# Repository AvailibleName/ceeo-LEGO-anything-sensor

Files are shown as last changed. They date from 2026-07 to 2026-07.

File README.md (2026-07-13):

## Bill of Materials (BOM)

To build the hardware for this device, you will need the following components:

- **Breadboard:** [Amazon Link](https://a.co/d/08REgV1U)
- **Microcontroller (Seeed XIAO nRF52840):** [Amazon Link](https://a.co/d/0hvDNsSc)
- **Battery:** [Amazon Link](https://a.co/d/0hvjeEuI)
- **RGB Button:** [Amazon Link](https://a.co/d/0b4CaRvc)
- **NFC Reader (MFRC522/WS1850S):** [Amazon Link](https://a.co/d/06IRiosf)
- **Misc:** Jumper wires, NFC cards/tags, and the actual sensors you wish to connect (e.g., VEML6040 Color Sensor, I2C OLED).

---

## Getting Started

### 1. Clone this Repository
First, download the repository so you have access to both the Arduino firmware and the Python library:
```bash
git clone https://github.com/AvailibleName/ceeo-LEGO-anything-sensor
cd ceeo-LEGO-anything-sensor
```
*(The Arduino code is located right in the root of this folder, and the custom Python library is in the `python_lib/` directory).*

---

## Wiring Guide

> [!IMPORTANT]
> You need to remove the housing from the NFC reader.

### Power
- **XIAO `3V3`** $\rightarrow$ Route power *directly* to the NFC Sensor VCC and RGB Button power (L1), since they are inside the housing and do not connect to the exposed breadboard. Also route `3V3` to the Breadboard VCC hookup for hot-swappable sensors.
- **XIAO `GND`** $\rightarrow$ Route ground *directly* to the NFC Sensor GND and RGB Button. Also route `GND` to the Breadboard GND hookup.

### RGB Button UI
- **XIAO `D0`** $\rightarrow$ Button contact/switch (Middle pin labeled **NO** on the switch)
- **XIAO `D1`** $\rightarrow$ Blue LED (Pin **L2** on the switch)
- **XIAO `D2`** $\rightarrow$ 100 $\Omega$ resistor $\rightarrow$ Green LED (Pin **L4** on the switch)
- **XIAO `D3`** $\rightarrow$ 100 $\Omega$ resistor $\rightarrow$ Red LED (Pin **L3** on the switch)
- **XIAO `3V3`** $\rightarrow$ Power (Pin **L1** on the switch)

### I2C Bus (Sensors & NFC)
- **XIAO `D4` (SDA)** $\rightarrow$ Route *separately* directly to the NFC Reader SDA, and also to the Breadboard SDA hookup.
- **XIAO `D5` (SCL)** $\rightarrow$ Route *separately* directly to the NFC Reader SCL, and also to the Breadboard SCL hookup.
*(Note: The custom sensors will be hot-swapped and their wiring will be connected to the hookups for I2C routed to the breadboard).*

---

## Build Instructions

1. **3D Printing the Housing** (files in `CAD/` folder): 
   - Print the main body housing **button-side-down** using **organic supports** set to **everywhere**.
   - The top plate should not need supports.
2. **Wiring**: Wire all components according to the guide above.
3. **Flashing Firmware**: 
   - **Flash the Arduino firmware onto the XIAO *before* assembling the housing.** Once assembled, the tiny reset (RST) button on the XIAO used for entering Bootloader mode will not be accessible!
4. **Assembly**: 
   - Trim the tabs at the base of the Grove connector on the NFC reader.
   - Bend the Grove port upwards so that it does not stick out too far to put the top plate on.
   - Route the cables going up to the breadboard *before* sliding the breadboard into the bottom housing (it won't be accessible after).
   - Slide all components into the bottom housing.
   - Superglue the top plate to the opening.
   - Superglue two LEGO 6x2 plates to the top, and two more LEGO 6x2 plates to the bottom.

---

## Firmware Setup

1. **Install Arduino IDE**: Download and install the [Arduino IDE](https://www.arduino.cc/en/software).
2. **Add Board Manager URL**: Open Arduino IDE. Go to `File > Preferences` and add `https://adafruit.github.io/arduino-board-index/package_adafruit_index.json` to the "Additional Boards Manager URLs" field.
3. **Install Board Support**: Go to `Tools > Board > Boards Manager...`, search for `Adafruit nRF52`, and install the **Adafruit nRF52 by Adafruit** package.
4. **Select Board**: Go to `Tools > Board > Adafruit nRF52 Boards` and select **Seeed XIAO nRF52840**.
5. **Install Libraries**: Go to `Tools > Manage Libraries...` and ensure you have any required libraries installed (e.g., `Adafruit TinyUSB Library` should be installed by the board package, but verify if needed).
6. **Flash the Code**: Open the `LegoSmartSensor.ino` file (located in the folder you just cloned) in the Arduino IDE, select the correct COM port under `Tools > Port`, and click the **Upload** arrow to flash the firmware to the XIAO. 

> [!TIP]
> If you ever need to flash new firmware after the device is assembled, hold the RGB button down for **10 seconds** while the device is on. The light will turn solid blue, and the device will reboot into DFU Bootloader mode, allowing you to upload code over USB.

---

## Software Setup (Python)

To communicate with the hardware, we use a fork of the `legoeducation` Python library that has been extended to support our custom sensors. For documentation on the original base library, refer to the [LEGOEducation GitHub](https://github.com/LEGO/LEGOEducation/blob/main/README.md).

### 1. Set up a Virtual Environment
We recommend creating a Python virtual environment inside the cloned folder to house the custom library:

```bash
# Create the virtual environment (use --system-site-packages if you have Bleak installed globally)
python3 -m venv --system-site-packages venv

# Activate it
source venv/bin/activate
```

### 2. Install the Custom Library
The custom library is located in the `python_lib/legoeducation` folder of this repository. You can copy it directly into your virtual environment:

```bash
cp -r python_lib/legoeducation venv/lib/python3.14/site-packages/
```
*(Make sure to adjust `python3.14` to match your actual Python version!)*

### 3. Running the Example
Once activated, run the provided boilerplate connection script to test your connection:
```bash
python3 examples/example.py
```

---

## Custom Sensor Documentation

By extending the `legoeducation` library in this repo, we can support totally custom hardware modules. 
### Color Sensor (VEML6040)
- **Product ID**: `61` (Emulates the official LEGO SPIKE Color Sensor)
- **Features**: This firmware module reads data from a VEML6040 I2C sensor and packages it to behave *identically* to an official LEGO Color Sensor.
- **Usage**: Since it acts identically to the official hardware, you can just use the standard legoeducation `ColorSensor` class. Please refer directly to the [original LEGOEducation library documentation](https://github.com/LEGO/LEGOEducation/blob/main/README.md) for full instructions on how to use it!

### OLED Display (`OledSensor`)
- **Product ID**: `530`
- **Notification ID**: `20`
- **Features**: 2-way data flow over BLE. The XIAO routes raw payload bytes directly into the C++ `handleDataReceived()` function.
- **Python Methods Available**:
  - `oled.print_text("Hello World")`: Prints standard ASCII text to the screen.
  - `oled.write_array(data)`: Renders raw 2D pixel arrays.
  - `oled._send_commands(bytes([0x06]))`: Clears the display.
  - `oled._send_commands(bytes([0x05, col, page]))`: Sets cursor position.
  - `oled._send_commands(bytes([0x03]))`: Starts hardware scroll.
  - `oled._send_commands(bytes([0x04]))`: Stops hardware scroll.

---

## Adding Your Own Custom Sensors (AI Generator)

Because adding a completely custom sensor requires both writing a C++ driver for the microcontroller AND modifying the Python `legoeducation` library on your PC to parse the data, we have included an AI Prompt generator to do the heavy lifting for you!

You can find the AI prompt template in the `AI_SENSOR_PROMPT.md` file in the root of this repository. 

To use it:
1. Open `AI_SENSOR_PROMPT.md`.
2. Choose **Option 1** if you are using an agentic AI that can read your local files (like Cursor, Claude Code, or Antigravity), or **Option 2** if you are pasting into a web chatbot (like ChatGPT or Claude Web).
3. Fill in the bracketed placeholders (`[LIKE THIS]`) with the specific I2C address and details of the hardware module you want to add.
4. The AI will instantly generate the `MySensor.cpp` and `MySensor.h` files for your Arduino firmware, AND provide the exact Python snippets you need to paste into `python_lib/legoeducation/rpc_message.py` and `device.py` to seamlessly parse the new data!

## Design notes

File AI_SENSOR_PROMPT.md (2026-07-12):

# AI Prompt Generator: LEGO Smart Sensor Driver

This document contains two AI prompts depending on what kind of AI you are using.

**Before you copy either prompt, make sure to replace the bracketed placeholders `[LIKE THIS]` with your specific sensor details!**

---

## Option 1: For Agentic AI (Antigravity, Claude Code, Cursor)
Use this prompt if the AI **has access to your local filesystem** and can read your code directly.

**[COPY BELOW THIS LINE]**

I am building a custom C++ firmware for a Seeed XIAO nRF52840 that emulates a LEGO Education sensor brick (like a Color Sensor, Matrix Display, or Distance Sensor) over BLE. 

The repository is located here: **[INSERT REPOSITORY FILEPATH HERE, e.g., /home/user/LegoSmartSensor]**

Please explore the repository and read all the `.cpp`, `.h`, and `.ino` files (especially `sensor_base.h`, `ble_emulator.cpp`, and the Python code in `python_lib/legoeducation`) to fully understand how the architecture handles device auto-detection, BLE notification packing, and 2-way data routing.

I need you to write a custom sensor driver for this hardware:
- **My Sensor/Addon Name:** [INSERT YOUR SENSOR NAME/MODEL HERE, e.g., TCS34725 I2C Color Sensor]
- **My Sensor's I2C Address:** [INSERT I2C ADDRESS, e.g., 0x29]
- **The specific data I want to extract/send:** [INSERT WHAT DATA YOU WANT, e.g., "I want to extract raw RGB values and convert them to HSV."]

Please implement the C++ `.cpp` and `.h` files inheriting from `LegoSensor`, and the Python payload/device classes for the `legoeducation` library.

**CRITICAL RULES & COMMON ISSUES TO AVOID:**
1. **No I2C Timeouts:** The Adafruit nRF52 Arduino Core's `TwoWire` class does **NOT** support `Wire.setWireTimeout()`. Do not attempt to use it or the code will fail to compile.
2. **No Serial Blocking:** This device often runs on battery power disconnected from USB. Never use `while(!Serial)` or any blocking serial wait loops, as this will completely freeze the device when unplugged. Always use safe wrappers like `if (Serial) { Serial.print(...); }`.
3. **Graceful Disconnects:** Ensure your `isConnected()` function correctly catches if the device is suddenly unplugged from the I2C bus, and ensure the main `buildNotification()` loop does not hang indefinitely waiting for bytes from an unresponsive I2C sensor.
4. **Integration:** Tell me exactly what lines to add to `SensorManager::detectSensors()` and where to inject the Python code.

---

## Option 2: For Chatbots (ChatGPT, Claude Web, Gemini)
Use this prompt if the AI **does not have access to your filesystem** and needs the architecture explained to it.

**[COPY BELOW THIS LINE]**

I am building a custom C++ firmware for a Seeed XIAO nRF52840 that emulates a LEGO Education sensor brick (like a Color Sensor, Matrix Display, or Distance Sensor) over BLE. 

I need you to write a custom sensor driver class that I can drop into my firmware.

### 1. The Target Hardware
- **My Microcontroller:** Seeed XIAO nRF52840 (Arduino Core)
- **My Sensor/Addon Name:** [INSERT YOUR SENSOR NAME/MODEL HERE, e.g., TCS34725 I2C Color Sensor]
- **My Sensor's I2C Address:** [INSERT I2C ADDRESS, e.g., 0x29]
- **The specific data I want to extract/send:** [INSERT WHAT DATA YOU WANT, e.g., "I want to extract raw RGB values and convert them to HSV."]

### 2. The Firmware Architecture
The firmware is already written and has an automatic hardware-detection system. It works like this:
1. `SensorManager` continuously polls the I2C bus. If it detects a device at a specific I2C address, it swaps a global pointer to use that specific sensor's driver class.
2. The `BleEmulator` automatically calls `buildNotification()` on the active sensor 10 times a second.
3. The `BleEmulator` automatically wraps the output of `buildNotification()` into the standard LEGO `DEVICE_NOTIFICATION` (MsgID 60) envelope, so the sensor driver ONLY needs to provide the sensor-specific inner payload bytes.

### 3. The Required Interface
You must create a `.h` and `.cpp` file for a class that inherits from this exact `LegoSensor` interface:

```cpp
#ifndef SENSOR_BASE_H
#define SENSOR_BASE_H
#include <Arduino.h>

class LegoSensor {
public:
    virtual ~LegoSensor() = default;
    virtual void begin() = 0;
    virtual uint16_t getProductId() = 0;
    virtual bool isConnected() { return true; }
    virtual void buildNotification(uint8_t* buffer, size_t& length) = 0;
    virtual void handleDataReceived(const uint8_t* payload, size_t length) {}
};
#endif
```

### 4. Critical Rules & Common Issues
1. **No I2C Timeouts:** The Adafruit nRF52 Arduino Core's `TwoWire` class does **NOT** support `Wire.setWireTimeout()`. Do not attempt to use it or the code will fail to compile.
2. **No Serial Blocking:** This device often runs on battery power disconnected from USB. Never use `while(!Serial)` or any blocking serial wait loops, as this will completely freeze the device when unplugged. Always use safe wrappers like `if (Serial) { Serial.print(...); }`.
3. **Graceful Disconnects:** Ensure your `isConnected()` function correctly catches if the device is suddenly unplugged from the I2C bus. Ensure `buildNotification()` doesn't hang in a `while` loop waiting for I2C bytes.

### Your Task
1. **Write the C++ Header (`MySensor.h`)**: Define the class inheriting from `LegoSensor`. 
2. **Write the C++ Implementation (`MySensor.cpp`)**: 
   - Implement `begin()` using standard Arduino `Wire` commands.
   - Implement `isConnected()` by doing a quick `Wire.beginTransmission(address); return (Wire.endTransmission() == 0);`.
   - Implement `buildNotification()`. The very first byte `buffer[0]` MUST be a unique Message ID (e.g., 20) that we will define for this sensor.
   - **(Optional for 2-way data)**: Override `virtual void handleDataReceived(const uint8_t* payload, size_t length)` to parse incoming commands from the host PC.
3. **Write the Python `rpc_message.py` additions**:
   - Provide the Python code to define the `PRODUCT_GROUP_DEVICE_[NAME]` constant.
   - Provide the `[NAME]_NOTIFICATION = 20` constant.
   - Provide the `class [Name]Notification:` Python class that uses the `struct` module to unpack the exact byte payload you designed in step 2.
4. **Write the Python `device.py` additions**:
   - Provide the `class [Name](_BasicDevice):` Python class. 
   - Set `self.product_id` to your new constant.
   - Add `@property` getters to easily read the unpacked data from `self.sensor`.
   - **(Optional for 2-way data)**: Add Python methods (e.g., `def print_text(self, text):`) that use `self.send(struct.pack(...))` to blast the data directly to the Xiao over Bluetooth.
5. **Integration Instructions**: Briefly explain where to paste the C++ code (in `SensorManager::detectSensors()`) and where to paste the Python code (in the `legoeducation` library files).

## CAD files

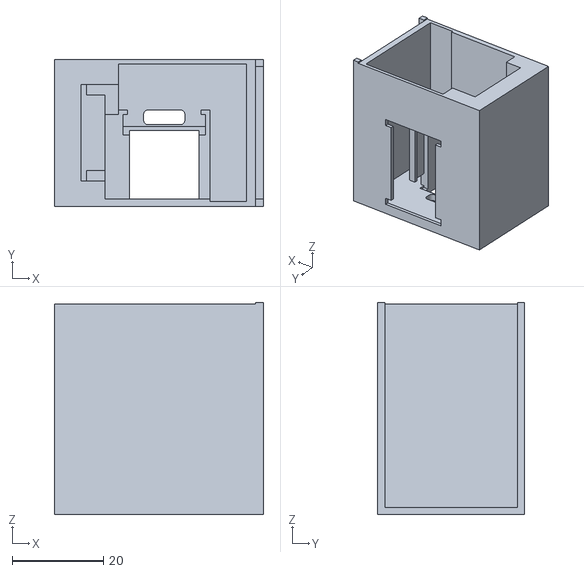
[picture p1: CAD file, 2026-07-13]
CAD/Main Body V3.6.stl
45.7 x 32.1 x 46.4

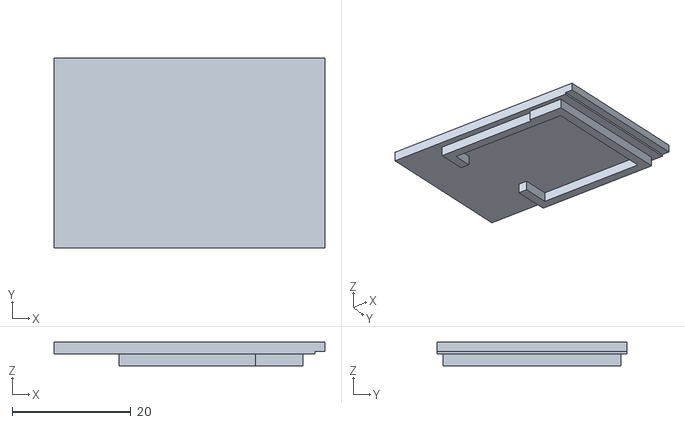
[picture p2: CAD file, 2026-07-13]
CAD/Top Plate V3 .6.stl
45.7 x 32.0 x 4.00

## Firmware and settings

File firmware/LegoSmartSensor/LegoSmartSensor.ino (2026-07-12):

#include "debug.h"
#include <Arduino.h>
#include <Wire.h>
#include "power_ui.h"
#include "sensor_manager.h"
#include "ble_emulator.h"

// Define Hardware Pins for Seeed XIAO nRF52840
#define BTN_PIN D0
#define LED_R D3
#define LED_G D2
#define LED_B D1

void setup() {
    // CRITICAL for battery operation: Allow time for external sensors (PN532, VEML6040)
    // to physically power up and stabilize before we attempt to talk to them over I2C.
    // Without this, I2C devices can lock the bus if they are polled while still booting.
    delay(2000);

    Serial.begin(115200);
    
    DEBUG_PRINTLN("LEGO Smart Sensor Emulator starting...");

    // Initialize Wire for I2C (default SDA=D4, SCL=D5 on XIAO)
    Wire.begin();

    // Initialize UI and Power Management
    PowerUI::begin(BTN_PIN, LED_R, LED_G, LED_B);

    // Initialize Sensor Manager and PN532
    SensorManager::begin();

    // Initialize BLE Emulator
    BleEmulator::begin();

    // Wire up UI callbacks

    PowerUI::setPairingToggledCallback([](bool pairingOn) {
        if (pairingOn) {
            BleEmulator::startAdvertising();
        } else {
            BleEmulator::stopAdvertising();
        }
    });

    DEBUG_PRINTLN("System Ready.");
}

void loop() {
    // 1. Process Button and UI State Machine
    PowerUI::loop();
    
    UIState state = PowerUI::getState();

    // 2. Run background tasks
    // Read NFC tags
    SensorManager::loop();
    
    // Handle BLE notifications if connected
    BleEmulator::loop();
    
    // Give FreeRTOS/SoftDevice a moment to breathe
    delay(5);
}

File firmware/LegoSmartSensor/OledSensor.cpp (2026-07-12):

#include "OledSensor.h"

static const uint8_t font5x7[95][5] = {
    { 0x00, 0x00, 0x00, 0x00, 0x00 },
    { 0x00, 0x00, 0x2f, 0x00, 0x00 },
    { 0x00, 0x07, 0x00, 0x07, 0x00 },
    { 0x14, 0x7f, 0x14, 0x7f, 0x14 },
    { 0x24, 0x2a, 0x7f, 0x2a, 0x12 },
    { 0x23, 0x13, 0x08, 0x64, 0x62 },
    { 0x36, 0x49, 0x55, 0x22, 0x50 },
    { 0x00, 0x05, 0x03, 0x00, 0x00 },
    { 0x00, 0x1c, 0x22, 0x41, 0x00 },
    { 0x00, 0x41, 0x22, 0x1c, 0x00 },
    { 0x14, 0x08, 0x3e, 0x08, 0x14 },
    { 0x08, 0x08, 0x3e, 0x08, 0x08 },
    { 0x00, 0x50, 0x30, 0x00, 0x00 },
    { 0x08, 0x08, 0x08, 0x08, 0x08 },
    { 0x00, 0x60, 0x60, 0x00, 0x00 },
    { 0x20, 0x10, 0x08, 0x04, 0x02 },
    { 0x3e, 0x51, 0x49, 0x45, 0x3e },
    { 0x00, 0x42, 0x7f, 0x40, 0x00 },
    { 0x42, 0x61, 0x51, 0x49, 0x46 },
    { 0x21, 0x41, 0x45, 0x4b, 0x31 },
    { 0x18, 0x14, 0x12, 0x7f, 0x10 },
    { 0x27, 0x45, 0x45, 0x45, 0x39 },
    { 0x3c, 0x4a, 0x49, 0x49, 0x30 },
    { 0x01, 0x71, 0x09, 0x05, 0x03 },
    { 0x36, 0x49, 0x49, 0x49, 0x36 },
    { 0x06, 0x49, 0x49, 0x29, 0x1e },
    { 0x00, 0x36, 0x36, 0x00, 0x00 },
    { 0x00, 0x56, 0x36, 0x00, 0x00 },
    { 0x08, 0x14, 0x22, 0x41, 0x00 },
    { 0x14, 0x14, 0x14, 0x14, 0x14 },
    { 0x00, 0x41, 0x22, 0x14, 0x08 },
    { 0x02, 0x01, 0x51, 0x09, 0x06 },
    { 0x32, 0x49, 0x79, 0x41, 0x3e },
    { 0x7e, 0x11, 0x11, 0x11, 0x7e },
    { 0x7f, 0x49, 0x49, 0x49, 0x36 },
    { 0x3e, 0x41, 0x41, 0x41, 0x22 },
    { 0x7f, 0x41, 0x41, 0x22, 0x1c },
    { 0x7f, 0x49, 0x49, 0x49, 0x41 },
    { 0x7f, 0x09, 0x09, 0x09, 0x01 },
    { 0x3e, 0x41, 0x49, 0x49, 0x7a },
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
};


OledSensor::OledSensor() : _i2cAddress(0x3C), _cursorCol(0), _cursorPage(0) {}

void OledSensor::sendCommand(uint8_t cmd) {
    Wire.beginTransmission(_i2cAddress);
    Wire.write(0x00);
    Wire.write(cmd);
    Wire.endTransmission();
}

void OledSensor::sendData(const uint8_t* data, size_t len) {
    // Send data in chunks of 16 to avoid buffer overflow
    for(size_t i = 0; i < len; i+=16) {
        Wire.beginTransmission(_i2cAddress);
        Wire.write(0x40); // Data stream
        size_t chunk = (len - i) > 16 ? 16 : (len - i);
        for(size_t j = 0; j < chunk; j++) {
            Wire.write(data[i+j]);
        }
        Wire.endTransmission();
    }
}

void OledSensor::setCursor(uint8_t col, uint8_t page) {
    _cursorCol = col;
    _cursorPage = page;
    sendCommand(0xB0 + (page & 0x07)); // set page
    sendCommand(0x00 + (col & 0x0F)); // lower col
    sendCommand(0x10 + ((col >> 4) & 0x0F)); // upper col
}

void OledSensor::clearDisplay() {
    uint8_t zero[16] = {0};
    for(uint8_t p = 0; p < 8; p++) {
        setCursor(0, p);
        for(uint8_t i = 0; i < 128/16; i++) {
            sendData(zero, 16);
        }
    }
    setCursor(0,0);
}

void OledSensor::printChar(char c) {
    if(c < 32 || c > 126) return;
    const uint8_t* charData = font5x7[c - 32];
    sendData(charData, 5);
    uint8_t space[1] = {0x00};
    sendData(space, 1);
    _cursorCol += 6;
    if(_cursorCol > 122) {
        _cursorCol = 0;
        _cursorPage = (_cursorPage + 1) % 8;
        setCursor(_cursorCol, _cursorPage);
    }
}

void OledSensor::begin() {
    Wire.beginTransmission(_i2cAddress);
    Wire.write(0x00);
    Wire.write(0xAE); // Display OFF
    Wire.write(0xD5); Wire.write(0x80); // Clock divide
    Wire.write(0xA8); Wire.write(0x3F); // Mux ratio 64
    Wire.write(0xD3); Wire.write(0x00); // Display offset
    Wire.write(0x40); // Start line 0
    Wire.write(0x8D); Wire.write(0x14); // Charge pump enable
    Wire.write(0x20); Wire.write(0x02); // Memory mode: Page Addressing Mode
    Wire.write(0xA1); // Segment remap
    Wire.write(0xC8); // COM scan direction
    Wire.write(0xDA); Wire.write(0x12); // COM pins hardware config
    Wire.write(0x81); Wire.write(0xCF); // Contrast
    Wire.write(0xD9); Wire.write(0xF1); // Pre-charge
    Wire.write(0xDB); Wire.write(0x40); // VCOMH
    Wire.write(0xA4); // Output follows RAM
    Wire.write(0xA6); // Normal display
    Wire.write(0xAF); // Display ON
    Wire.endTransmission();
    
    clearDisplay();
}

uint16_t OledSensor::getProductId() {
    return 530; // PRODUCT_GROUP_DEVICE_OLED
}

bool OledSensor::isConnected() {
    Wire.beginTransmission(_i2cAddress);
    return (Wire.endTransmission() == 0);
}

void OledSensor::buildNotification(uint8_t* buffer, size_t& length) {
    buffer[0] = 20; // OLED_NOTIFICATION
    buffer[1] = 1;  // Status OK
    length = 2;
}

void OledSensor::handleDataReceived(const uint8_t* payload, size_t length) {
    if (length == 0) return;
    uint8_t cmd = payload[0];
    
    if (cmd == 0x01 && length >= 4) { // Write pixel array data
        // payload[1] = col, payload[2] = page, payload[3..] = data
        uint8_t col = payload[1];
        uint8_t page = payload[2];
        setCursor(col, page);
        sendData(&payload[3], length - 3);
    } 
    else if (cmd == 0x02 && length >= 2) { // Print text
        // payload[1..] = string
        for(size_t i = 1; i < length; i++) {
            printChar((char)payload[i]);
        }
    }
    else if (cmd == 0x03) { // Start hardware scroll right
        sendCommand(0x26); // Right horizontal scroll
        sendCommand(0x00); // Dummy byte
        sendCommand(0x00); // Start page
        sendCommand(0x07); // Time interval
        sendCommand(0x07); // End page
        sendCommand(0x00); // Dummy byte
        sendCommand(0xFF); // Dummy byte
        sendCommand(0x2F); // Activate scroll
    }
    else if (cmd == 0x04) { // Stop hardware scroll
        sendCommand(0x2E); // Deactivate scroll
    }
    else if (cmd == 0x05 && length >= 3) { // Set cursor
        setCursor(payload[1], payload[2]);
    }
    else if (cmd == 0x06) { // Clear display
        clearDisplay();
    }
}

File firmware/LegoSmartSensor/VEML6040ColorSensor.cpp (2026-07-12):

#include "VEML6040ColorSensor.h"
#include <math.h>

#ifndef max
#define max(a,b) ((a)>(b)?(a):(b))
#endif
#ifndef min
#define min(a,b) ((a)<(b)?(a):(b))
#endif

VEML6040ColorSensor::VEML6040ColorSensor() {
}

void VEML6040ColorSensor::begin() {
    Wire.beginTransmission(VEML6040_I2C_ADDR);
    Wire.write(REG_CONF);
    // Config: Auto mode, 40ms integration time (0x00)
    Wire.write(0x00);
    Wire.write(0x00);
    Wire.endTransmission();
}

uint16_t VEML6040ColorSensor::getProductId() {
    return 514; // PRODUCT_GROUP_DEVICE_COLOR_SENSOR
}

bool VEML6040ColorSensor::isConnected() {
    Wire.beginTransmission(VEML6040_I2C_ADDR);
    return (Wire.endTransmission() == 0);
}

uint16_t VEML6040ColorSensor::readRegister16(uint8_t reg) {
    Wire.beginTransmission(VEML6040_I2C_ADDR);
    Wire.write(reg);
    Wire.endTransmission(false);
    Wire.requestFrom(VEML6040_I2C_ADDR, (uint8_t)2);
    
    if (Wire.available() >= 2) {
        uint8_t lsb = Wire.read();
        uint8_t msb = Wire.read();
        return (msb << 8) | lsb;
    }
    return 0;
}

void VEML6040ColorSensor::rgbToHsv(uint16_t r, uint16_t g, uint16_t b, uint16_t& h, uint8_t& s, uint8_t& v) {
    // Normalize to 0.0 - 1.0 (assuming 16-bit color maxes around 65535, 
    // but practically indoors it might max out lower, so we scale relative to the max of the three)
    float max_rgb = max(r, max(g, b));
    if (max_rgb == 0) {
        h = 0; s = 0; v = 0;
        return;
    }

    float rf = r / max_rgb;
    float gf = g / max_rgb;
    float bf = b / max_rgb;

    float cmax = max(rf, max(gf, bf));
    float cmin = min(rf, min(gf, bf));
    float delta = cmax - cmin;

    float h_float = 0;
    if (delta == 0) {
        h_float = 0;
    } else if (cmax == rf) {
        h_float = 60.0f * fmod(((gf - bf) / delta), 6.0f);
    } else if (cmax == gf) {
        h_float = 60.0f * (((bf - rf) / delta) + 2.0f);
    } else if (cmax == bf) {
        h_float = 60.0f * (((rf - gf) / delta) + 4.0f);
    }

    if (h_float < 0) h_float += 360.0f;

    float s_float = (cmax == 0) ? 0 : (delta / cmax);
    
    // Scale value based on max_rgb relative to a reasonable indoor brightness (e.g., 10000)
    // Cap at 1.0
    float v_float = max_rgb / 10000.0f;
    if (v_float > 1.0f) v_float = 1.0f;

    h = (uint16_t)h_float;
    s = (uint8_t)(s_float * 100.0f);
    v = (uint8_t)(v_float * 100.0f);
}

int8_t VEML6040ColorSensor::matchLegoColor(uint16_t h, uint8_t s, uint8_t v) {
    // LEGO Firmware Colors:
    // -1 = None, 0 = Black, 1 = Magenta, 2 = Purple, 3 = Blue, 4 = Azure,
    // 5 = Turquoise, 6 = Green, 7 = Yellow, 8 = Orange, 9 = Red, 10 = White
    
    // Ambient light significantly desaturates reflective colors without a dedicated LED.
    // We must relax the Saturation and Value thresholds.
    if (v < 3) return 0; // Black
    if (s < 10 && v > 70) return 10; // White
    if (s < 5) return -1; // None (Gray)

    if (h < 20 || h >= 345) return 9; // Red
    if (h >= 20 && h < 50) return 8; // Orange
    if (h >= 50 && h < 85) return 7; // Yellow
    if (h >= 85 && h < 150) return 6; // Green
    if (h >= 150 && h < 180) return 5; // Turquoise
    if (h >= 180 && h < 210) return 4; // Azure
    if (h >= 210 && h < 260) return 3; // Blue
    if (h >= 260 && h < 290) return 2; // Purple
    if (h >= 290 && h < 345) return 1; // Magenta

    return -1; // Fallback
}

void VEML6040ColorSensor::buildNotification(uint8_t* buffer, size_t& length) {
    // ColorSensorNotification Format:
    // Header (1 byte, ID = 12)
    // FormatString = "<bBHHHHBB"
    // (color, reflection, rawRed, rawGreen, rawBlue, hue, saturation, value)
    
    uint16_t rawRed = readRegister16(REG_R_DATA);
    uint16_t rawGreen = readRegister16(REG_G_DATA);
    uint16_t rawBlue = readRegister16(REG_B_DATA);
    
    // Apply a simple white-balance calibration based on testing.
    // The user found that Red * 1.065 and Blue * 2.7 perfectly aligns the channels!
    uint32_t calibratedRed = (uint32_t)(rawRed * 1.065f);
    if (calibratedRed > 65535) calibratedRed = 65535;
    rawRed = (uint16_t)calibratedRed;

    uint32_t calibratedBlue = (uint32_t)(rawBlue * 2.7f);
    if (calibratedBlue > 65535) calibratedBlue = 65535;
    rawBlue = (uint16_t)calibratedBlue;
    
    uint16_t hue = 0;
    uint8_t saturation = 0;
    uint8_t value = 0;
    
    rgbToHsv(rawRed, rawGreen, rawBlue, hue, saturation, value);
    
    int8_t color = matchLegoColor(hue, saturation, value); 
    uint8_t reflection = value; // Use 'value' as a proxy for reflection

    buffer[0] = 12; // COLOR_SENSOR_NOTIFICATION
    buffer[1] = color;
    buffer[2] = reflection;
    buffer[3] = rawRed & 0xFF;
    buffer[4] = rawRed >> 8;
    buffer[5] = rawGreen & 0xFF;
    buffer[6] = rawGreen >> 8;
    buffer[7] = rawBlue & 0xFF;
    buffer[8] = rawBlue >> 8;
    buffer[9] = hue & 0xFF;
    buffer[10] = hue >> 8;
    buffer[11] = saturation;
    buffer[12] = value;
    
    length = 13;
}

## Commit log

2026-07-12 Initial commit: LEGO anything sensor and Custom Python Library
2026-07-13 Add CAD files and change folder structure
    [Main Body V3.6.stl, Top Plate V3 .6.stl]
2026-07-13 Update BOM in readme
